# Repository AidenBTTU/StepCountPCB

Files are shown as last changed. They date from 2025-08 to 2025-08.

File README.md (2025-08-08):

# StepCountPCB
Custom PCB for a step counting device with I2C and USB communication, an external crystal oscillator, and a power system with battery charging capabilities





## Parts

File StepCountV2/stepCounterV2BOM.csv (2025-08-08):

Value | Designator | Footprint | LCSC Part Number
FerriteBead | FB1 | Inductor_SMD:L_0603_1608Metric | C41330
10uF | C1 | Capacitor_SMD:C_0603_1608Metric | C1691
100nF | C2,C3,C4,C5,C9,C10,C11 | Capacitor_SMD:C_0402_1005Metric | C1581
10nF | C6,C8 | Capacitor_SMD:C_0402_1005Metric | C1524
1uF | C7,C16 | Capacitor_SMD:C_0603_1608Metric | C52923
10pF | C12,C13 | Capacitor_SMD:C_0402_1005Metric | C1545
4.7uF | C14,C15,C17 | Capacitor_SMD:C_0603_1608Metric | C19666
LED | D1 | LED_SMD:LED_0603_1608Metric | C2286
USB_B_Micro | J1 | Connector_USB:USB_Micro-B_Wuerth_629105150521 | C2894326
SWLINK | J2 | Connector_PinSocket_2.54mm:PinSocket_1x04_P2.54mm_Vertical | C2691448
JST PH | J5 | Connector_JST:JST_PH_S2B-PH-K_1x02_P2.00mm_Horizontal | C173752
10k | R1,R8,R11,R12 | Resistor_SMD:R_0402_1005Metric | C25744
2k2 | R2,R3,R4,R5,R6,R7 | Resistor_SMD:R_0402_1005Metric | C25879
1k5 | R4 | Resistor_SMD:R_0402_1005Metric | C22369162
1k | R9 | Resistor_SMD:R_0402_1005Metric | C11702
2k | R10 | Resistor_SMD:R_0402_1005Metric | C4109
SW_SPDT | SW1,SW3 | Button_Switch_SMD:SW_SPDT_PCM12 | C221841
SW_NRST | SW2 | Button_Switch_SMD:SW_SPST_PTS647_Sx38 | C318886
STM32F103C8Tx | U1 | Package_QFP:LQFP-48_7x7mm_P0.5mm | C8734
BMA400 | U2 | BMA400:XDCR_BMA400 | C437655
BQ24092DGQR | U4 | BQ24092DGQR:IC_XTR111AIDGQR | C133237
TPS7A0533PDBV | U5 | Package_TO_SOT_SMD:SOT-23-5 | C493453
16Mhz | Y1 | Crystal:Crystal_SMD_3225-4Pin_3.2x2.5mm | C112972

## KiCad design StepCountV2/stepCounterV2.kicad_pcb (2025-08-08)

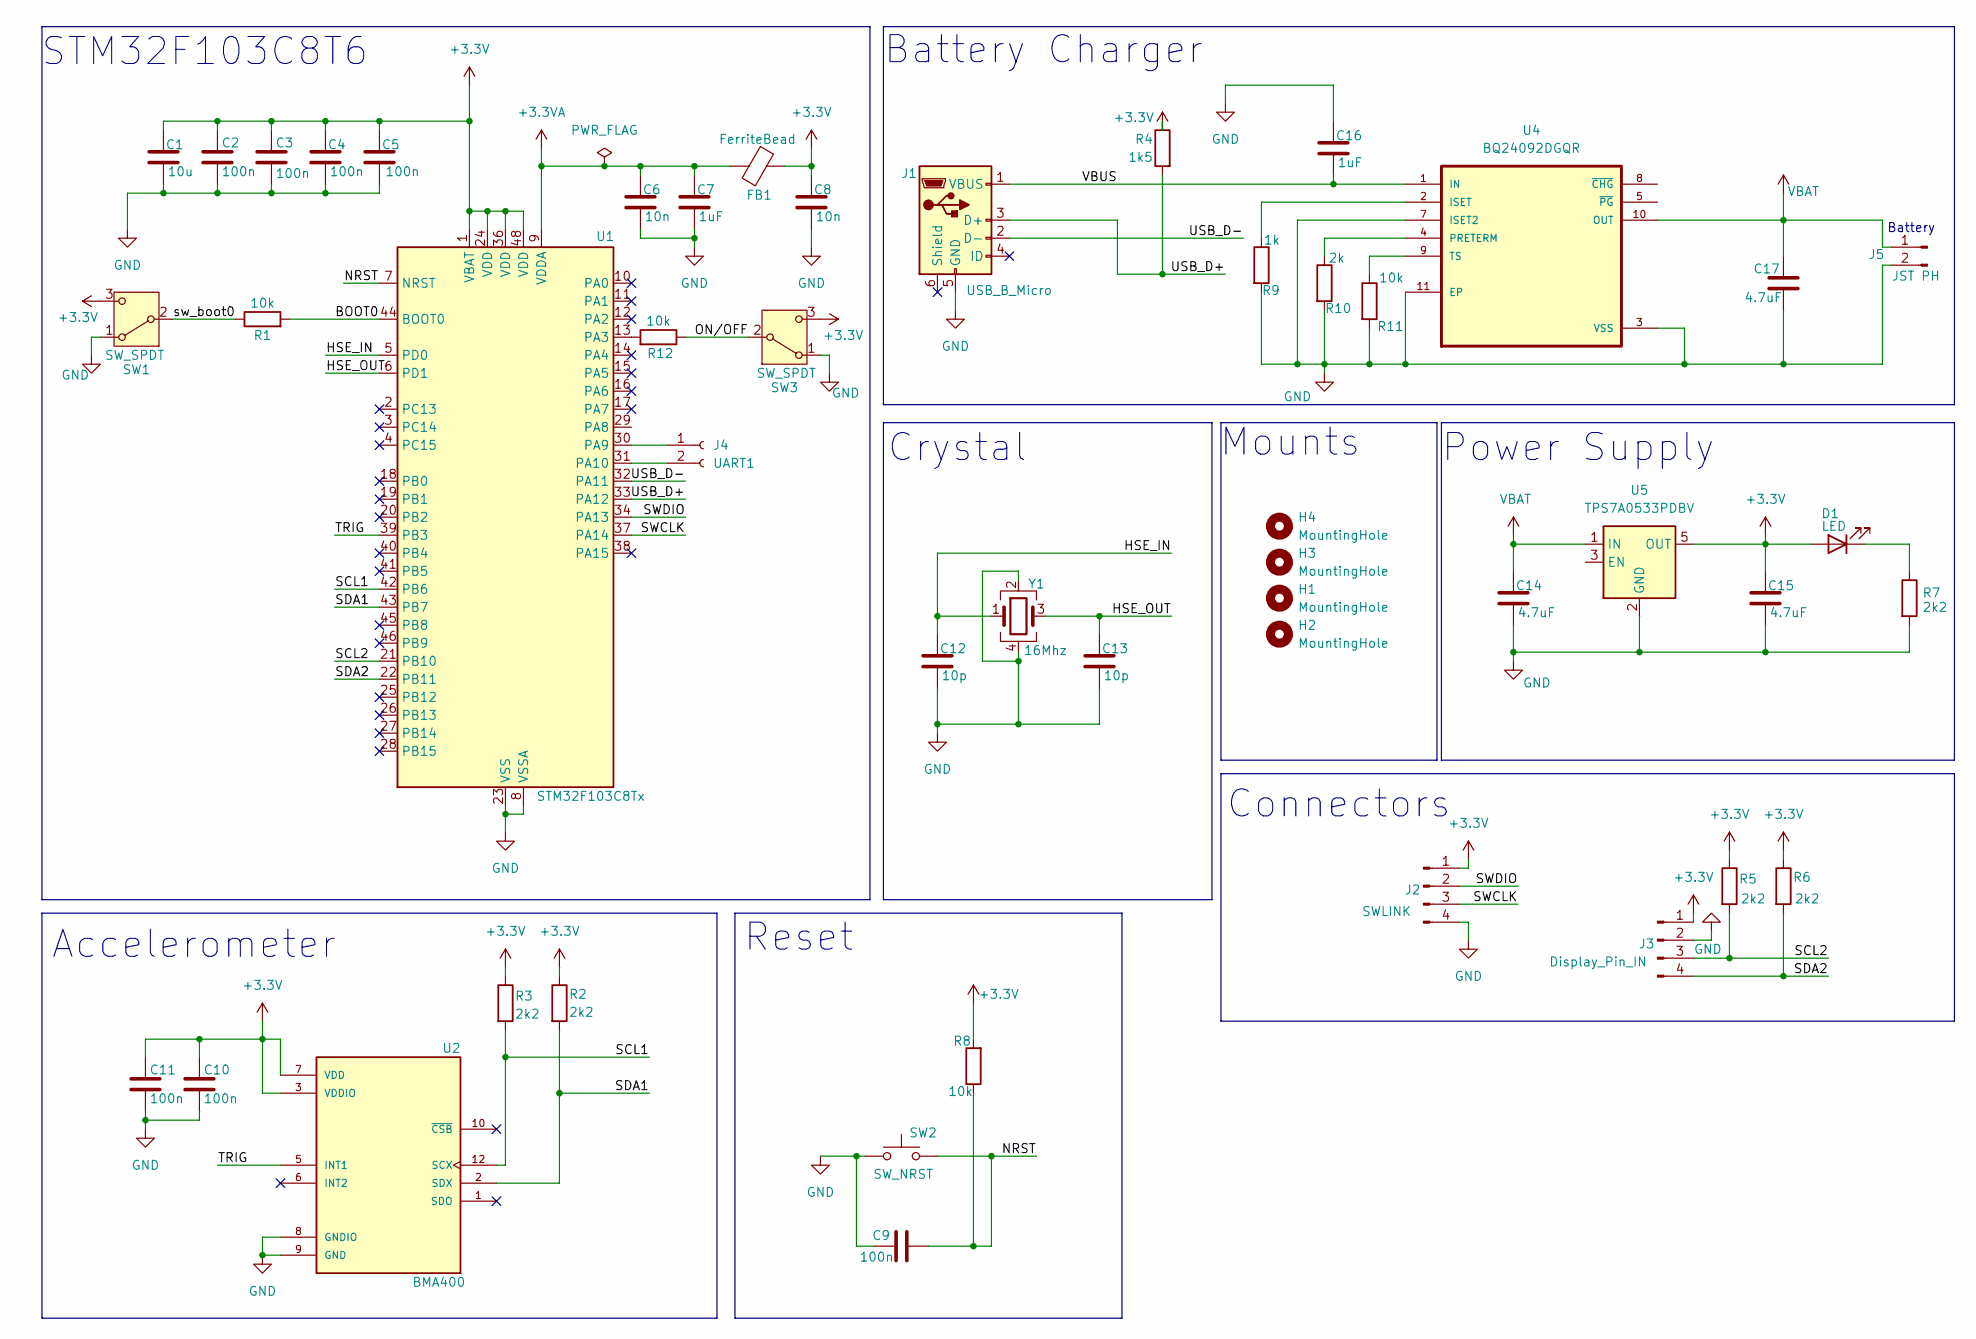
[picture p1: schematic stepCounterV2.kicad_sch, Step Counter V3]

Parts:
C1: 10u; C_0603_1608Metric
C2, C3, C4, C5, C9, C10, C11: 100n; C_0402_1005Metric
C6, C8: 10n; C_0402_1005Metric
C7, C16: 1uF; C_0603_1608Metric
C12, C13: 10p; C_0402_1005Metric
C14, C15, C17: 4.7uF; C_0603_1608Metric
D1: LED; LED_0603_1608Metric
FB1: FerriteBead; L_0603_1608Metric
H1, H2, H3, H4: MountingHole; MountingHole_2.2mm_M2
J1: USB_B_Micro; USB_Micro-B_Wuerth_629105150521
J2: SWLINK; PinSocket_1x04_P2.54mm_Vertical
J3: Display_Pin_IN; PinSocket_1x04_P2.54mm_Vertical
J4: UART1; PinSocket_1x02_P2.54mm_Vertical
J5: JST PH; JST_PH_S2B-PH-K_1x02_P2.00mm_Horizontal
R1, R8, R11, R12: 10k; R_0402_1005Metric
R2, R3, R5, R6, R7: 2k2; R_0402_1005Metric
R4: 1k5; R_0402_1005Metric
R9: 1k; R_0402_1005Metric
R10: 2k; R_0402_1005Metric
SW1, SW3: SW_SPDT; SW_SPDT_PCM12
SW2: SW_NRST; SW_SPST_PTS647_Sx38
U1: STM32F103C8Tx; LQFP-48_7x7mm_P0.5mm
U2: BMA400; XDCR_BMA400
U4: BQ24092DGQR; IC_XTR111AIDGQR
U5: TPS7A0533PDBV; SOT-23-5
Y1: 16Mhz; Crystal_SMD_3225-4Pin_3.2x2.5mm

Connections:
+3.3V: C1.1, C2.1, C3.1, C4.1, C5.1, C8.1, C10.1, C11.1, C15.1, D1.2 (A), FB1.1, J2.1, J3.1, R2.1, R3.1, R4.1, R5.1, R6.1, R8.2, SW1.3 (C), SW3.3 (C), U1.1 (VBAT), U1.24 (VDD), U1.36 (VDD), U1.48 (VDD), U2.3 (VDDIO), U2.7 (VDD), U5.5 (OUT)
+3.3VA: C6.1, C7.1, FB1.2, U1.9 (VDDA)
/ SCL1: R3.2, U1.42 (PB6), U2.12 (SCX)
/ SCL2: J3.3, R5.2, U1.21 (PB10)
/ SDA1: R2.2, U1.43 (PB7), U2.2 (SDX)
/ SDA2: J3.4, R6.2, U1.22 (PB11)
/ SWCLK: J2.3, U1.37 (PA14)
/ SWDIO: J2.2, U1.34 (PA13)
/BOOT0: R1.2, U1.44 (BOOT0)
/HSE_IN: C12.1, U1.5 (PD0), Y1.1
/HSE_OUT: C13.1, U1.6 (PD1), Y1.3
/NRST: C9.2, R8.1, SW2.2, U1.7 (NRST)
/ON/OFF: R12.1, SW3.2 (B)
/TRIG: U1.39 (PB3), U2.5 (INT1)
/USB_D+: J1.3 (D+), R4.2, U1.33 (PA12)
/USB_D-: J1.2 (D-), U1.32 (PA11)
/VBUS: C16.2, J1.1 (VBUS), U4.1 (IN)
/sw_boot0: R1.1, SW1.2 (B)
GND: C1.2, C2.2, C3.2, C4.2, C5.2, C6.2, C7.2, C8.2, C9.1, C10.2, C11.2, C12.2, C13.2, C14.2, C15.2, C16.1, C17.2, J1.5 (GND), J2.4, J3.2, J5.2, R7.2, R9.2, R10.2, R11.2, SW1.1 (A), SW2.1, SW3.1 (A), U1.8 (VSSA), U1.23 (VSS), U1.35 (VSS), U1.47 (VSS), U2.8 (GNDIO), U2.9 (GND), U4.3 (VSS), U4.7 (ISET2), U4.11 (EP), U4.12, U4.13, U4.14, U4.15, U4.16, U5.2 (GND), Y1.2, Y1.4
unnamed: D1.1 (K), R7.1
unnamed: J4.1, U1.30 (PA9)
unnamed: J4.2, U1.31 (PA10)
unnamed: R12.2, U1.13 (PA3)
unnamed: R9.1, U4.2 (ISET)
unnamed: R10.1, U4.4 (PRETERM)
unnamed: R11.1, U4.9 (TS)
VBAT: C14.1, C17.1, J5.1, U4.10 (OUT), U5.1 (IN)

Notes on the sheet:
Connectors
Accelerometer
Power Supply
Battery Charger
Mounts
Crystal
Reset
Battery
STM32F103C8T6

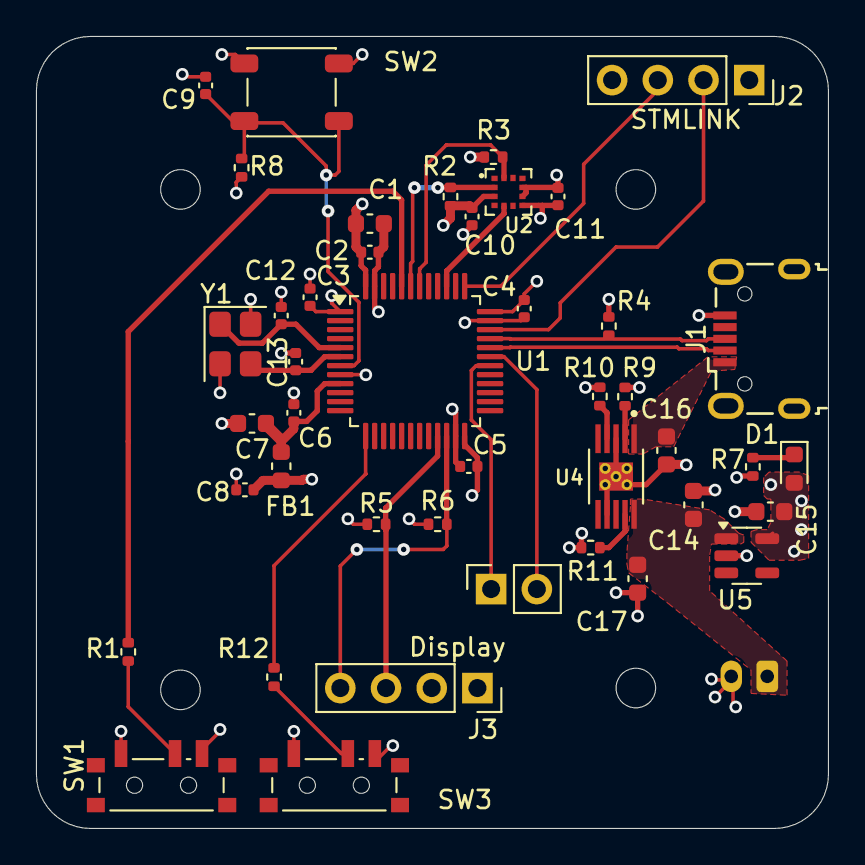
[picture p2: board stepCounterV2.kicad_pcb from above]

Board: 4 copper layers, 44.0 x 44.0 mm, 48 parts (1 on the bottom side), 27 nets.

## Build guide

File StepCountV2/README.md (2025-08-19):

The Second version of this project

New Features: NRST Button, STMLink, UART1, Battery charging circuit, 4 Layer w/ 2 power planes

Problems: Enable pin on TPS7A0533PDBV(voltage regulator) not pulled to VBAT, SDO pin on BMA400 not pulled to GND or 3.3V leaving the address of the BMA400 unknown



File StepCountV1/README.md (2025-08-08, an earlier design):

The first version of this project. 

New Features: This version includes a boot switch, a BMA400 accelerometer, a micro USB connection, and pinned-out I2C communication pins for a connected Display 

Discovered Problems: The MCU being used in this project, the STM32F103C8T6 does not come with a bootloader that allows it to be flashed via USB. This rendered the original board unprogrammable in this edition. 



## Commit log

2025-08-08 Placement Files, Bill of Materials
    [BOM StepCounterV2 Final - stepCounterV2-JLCPCB Assembly Order.xls, BOM StepCounterV2 Final - stepCounterV2.csv]
2025-08-08 Update and rename stepCounterV2.kicad_pcb to stepCounterV1.kicad_pcb
    [stepCounterV1.kicad_pcb]
2025-08-08 Rename BOM StepCounterV2 Final - stepCounterV2-JLCPCB Assembly Order.xls to StepCounterV1Placement.xls
    [StepCounterV1Placement.xls]
2025-08-08 Update and rename BOM StepCounterV2 Final - stepCounterV2.csv to StepCounterV1BOM.csv
    [StepCounterV1BOM.csv]
2025-08-08 Update and rename stepCounterV2.kicad_sch to stepCounterV1.kicad_sch
    [stepCounterV1.kicad_sch]
2025-08-08 PCB files for V2
    [stepCounterV3.kicad_pcb, stepCounterV3.kicad_sch]
2025-08-08 Update and rename stepCounterV3.kicad_pcb to stepCounterV2.kicad_pcb
    [stepCounterV2.kicad_pcb]
2025-08-08 Update and rename stepCounterV3.kicad_sch to stepCounterV2.kicad_sch
    [stepCounterV2.kicad_sch]
2025-08-08 BOm and Placement
    [stepCounterV3BOMFinal3 - stepCounterV3.csv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]
2025-08-08 Update and rename stepCounterV3BOMFinal3 - stepCounterV3.csv to stepCounterV2BOM.csv
    [stepCounterV2BOM.csv]
2025-08-08 Update and rename PositionStepCounterV3Final2 - stepCounterV3-all-pos.csv to StepCounterV2POS.csv
    [StepCounterV2POS.csv]
